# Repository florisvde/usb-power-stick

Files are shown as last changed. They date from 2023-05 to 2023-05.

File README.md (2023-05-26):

# USB Power Stick
The USB Power Stick is a USB Stick to control power (up to 1 A) to a USB powered device from a PC or SBC.

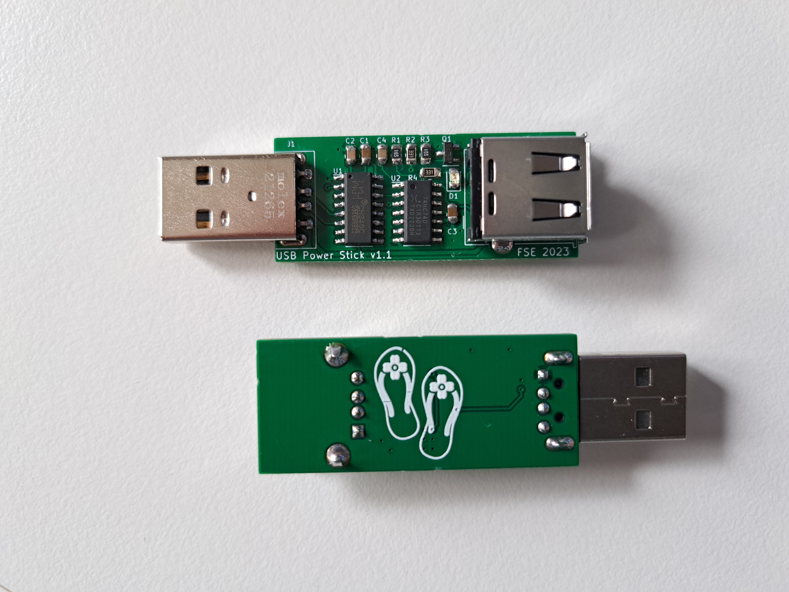
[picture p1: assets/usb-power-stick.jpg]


## Motivation
The Stick is inspired by the common [USB relay sticks](https://aliexpress.com/item/4001216792789.html). 
But using that stick to switch USB power on and off is messy: it requires cutting a USB extention cord, connecting the relay in between and takes up two USB ports. Leading to contraptions like this:

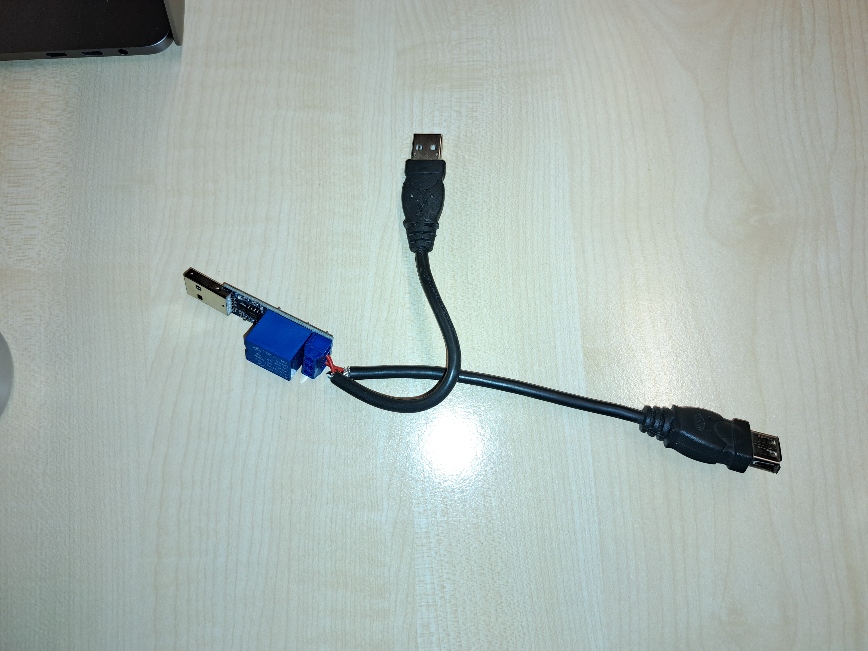
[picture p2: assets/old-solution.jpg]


The USB Power Stick solves that problem neatly by providing the switched power on a USB Type A socket. 

The Stick is used to turn an [IKEA HÅRTE](https://www.ikea.com/nl/nl/p/harte-led-bureaulamp-zwart-zilverkleur-20527242/) light on and off using a Python script running on a Raspberry Pi. The light is used to illuminate a 3D printer, controlled by Octoprint, so a webcam can track the printer's progression during the night.

## How does it work
Take a look at the [PDF of the schematic](https://github.com/florisvde/usb-power-stick/blob/main/KiCad/usb-power-stick/usb-power-stick-schematic.pdf). 
The Stick makes use of a USB to serial converter, a flip flop and an output transistor to switch power on and off to the device connected to the Stick's output. The Stick does not provide USB connectivity to the Stick's output.

The RTS line of the serial converter can be controlled from a computer while the port is open. Therefore the RTS line is connected to the flip flop's (FF) data input (D) and the TX line to the FF's clock input (C). By sending a character the FF latches the current RTS state to the FF's output (Q), then the port can be closed again. This allows for a script to periodically turn power to the device on or off when needed.

An RC network is connected to the FF's asynchronous ~R input, to make sure the stick starts up in the off state, a so called Power on Reset (PoR) circuit.

## Build your own
You can send the Gerber files (directly downloadable as zip from the [releases page](https://github.com/florisvde/usb-power-stick/releases)) to any PCB manufacturer and have the boards made. The board is designed with manual assembly in mind, all parts are easily soldered using a standard soldering iron, fine solder and a pair of tweezers. For everything but the passives a shop link is provided in the [Bill of Materials (BOM)](https://github.com/florisvde/usb-power-stick/blob/main/KiCad/usb-power-stick/usb-power-stick-bom.md).
Pay attention to the pin 1 marker (triangle) of D1: the silk screened triangle is correct, the silk screened outline of the part is not!

## Use it
1. Install [Python](https://www.python.org/downloads/) for your OS.
1. Install the [PySerial package](https://pypi.org/project/pyserial/).
1. Plug the Stick into an computer.
1. Find the Stick's *device dev path* (Unix) by running `ls /dev/ttyUSB*` or *COM port* (Windows) by going to Device Manager.
1. Clone or download this repository.
1. Edit the `stick_on.py` and `stick_off.py` files to use the correct device dev path or COM port.
1. In the directory containing the scripts, run `python stick_on.py` to turn power to the load on, and run `python stick_off.py` to turn power to the load off.

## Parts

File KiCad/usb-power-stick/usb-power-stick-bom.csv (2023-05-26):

Reference | Value | Footprint | Datasheet | Farnell | link | Qty
C1, C3 | 100n | Resistor_SMD:R_0805_2012Metric | ~ | ~ | ~ | 2
C2 | 10n | Resistor_SMD:R_0805_2012Metric | ~ | ~ | ~ | 1
C4 | 1u | Resistor_SMD:R_0805_2012Metric | ~ | ~ | ~ | 1
D1 | LED | LED_SMD:LED_0805_2012Metric | https://www.farnell.com/datasheets/622356.pdf | 1318244 | https://nl.farnell.com/1318244 | 1
J1 | 48037-0001 | kicad_custom_parts:Molex_48037-0001 | https://www.japanese.molex.com/content/dam/molex/molex-dot-com/products/automated/en-us/salesdrawingpdf/480/48037/480370001_sd.pdf | 2067044 | https://nl.farnell.com/2067044 | 1
J2 | 67643-0910 | Connector_USB:USB_A_Molex_67643_Horizontal | https://www.japanese.molex.com/content/dam/molex/molex-dot-com/products/automated/en-us/salesdrawingpdf/676/67643/676430910_sd.pdf | 1450206 | https://nl.farnell.com/1450206 | 1
Q1 | IRLML2803TRPBF | Package_TO_SOT_SMD:SOT-23 | https://www.infineon.com/dgdl/Infineon-IRLML2803-DataSheet-v01_01-EN.pdf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 | 9102701 | https://nl.farnell.com/9102701 | 1
R1, R3 | 10k | Resistor_SMD:R_0805_2012Metric | ~ | ~ | ~ | 2
R2, R4 | 330 | Resistor_SMD:R_0805_2012Metric | ~ | ~ | ~ | 2
U1 | CH340C | Package_SO:SOIC-16_3.9x9.9mm_P1.27mm | http://www.wch-ic.com/downloads/CH340DS1_PDF.html |  | https://www.lcsc.com/product-detail/USB-ICs_WCH-Jiangsu-Qin-Heng-CH340C_C84681.html | 1
U2 | 74HC74 | Package_SO:SOIC-14_3.9x8.7mm_P1.27mm | https://assets.nexperia.com/documents/data-sheet/74HC_HCT74.pdf | 1201317 | https://nl.farnell.com/1201317 | 1

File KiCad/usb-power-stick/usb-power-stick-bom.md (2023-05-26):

| Reference	| Value 			| Farnell	| Quantity	| Shop link 																					| Datasheet link 	|
| --- | ---		| ---	| ---	| ---	| ---	|
| C1, C3 | 100n 				| - 		| 2 		| - 																							| - 				|
| C2		| 10n				| -			| 1			| - 																							| - 				|
| C4		| 1u				| -			| 1			| - 																							| - 				|
| D1[^1]	| LED				| 1318244	| 1			| [Farnell](https://nl.farnell.com/1318244) 													| [Datasheet](https://www.farnell.com/datasheets/622356.pdf) |
| J1		| 48037-0001		| 2067044	| 1			| [Farnell](https://nl.farnell.com/2067044) 													| [Datasheet](https://www.japanese.molex.com/content/dam/molex/molex-dot-com/products/automated/en-us/salesdrawingpdf/480/48037/480370001_sd.pdf) |
| J2		| 67643-0910		| 1450206	| 1			| [Farnell](https://nl.farnell.com/1450206) 													| [Datasheet]( https://www.japanese.molex.com/content/dam/molex/molex-dot-com/products/automated/en-us/salesdrawingpdf/676/67643/676430910_sd.pdf) |
| Q1		| IRLML2803TRPBF	| 9102701	| 1			| [Farnell](https://nl.farnell.com/9102701) 													| [Datasheet](https://www.infineon.com/dgdl/Infineon-IRLML2803-DataSheet-v01_01-EN.pdf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) |
| R1, R3	| 10k				| -			| 2			| - 																							| - 				|
| R2, R4	| 330				| -			| 2			| -	 																							| - 				|
| U1		| CH340C			| -			| 1			| [LCSC](https://www.lcsc.com/product-detail/USB-ICs_WCH-Jiangsu-Qin-Heng-CH340C_C84681.html) 	| [Datasheet](http://www.wch-ic.com/downloads/CH340DS1_PDF.html) |
| U2		| 74HC74			| 1201317	| 1			| [Farnell](https://nl.farnell.com/1201317)														| [Datasheet](https://assets.nexperia.com/documents/data-sheet/74HC_HCT74.pdf) |

[^1]: The Kingbright KP-2012SRC-PRV LED is End of Life (EOL). Kingbright recommends the [KP-2012SURCK](https://nl.farnell.com/1318245) as an alternative.

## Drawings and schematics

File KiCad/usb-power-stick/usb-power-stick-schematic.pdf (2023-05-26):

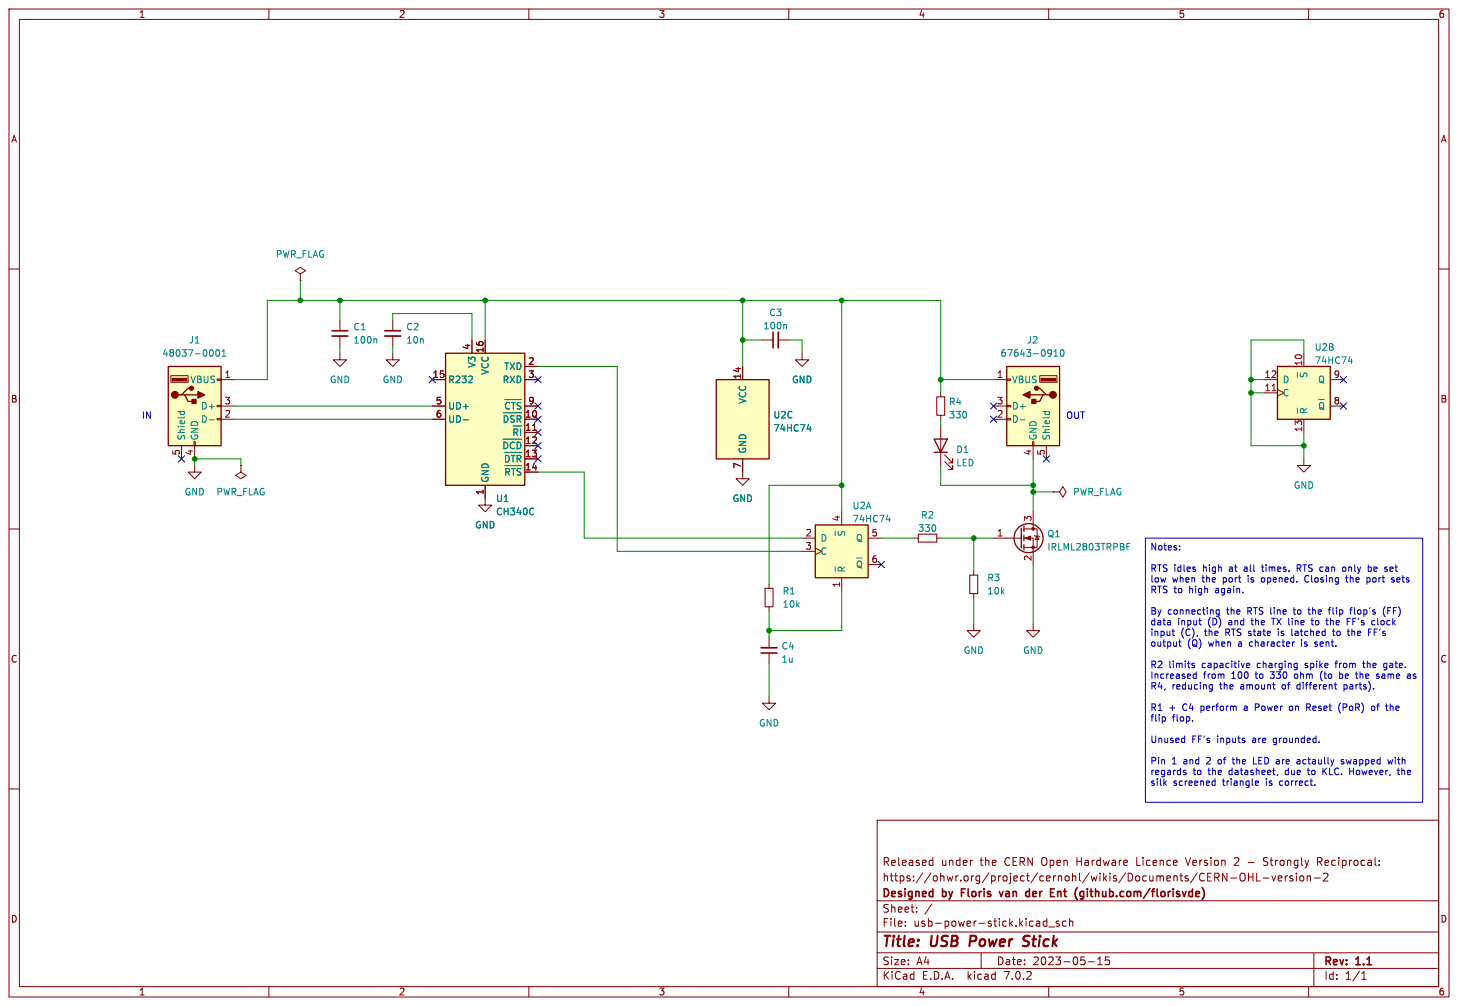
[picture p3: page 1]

1 ~{DSR} 10 ~{RI} 11 ~{DCD} 12 ~{DTR} 13 ~{RTS} 14 R232 15 VCC 16 TXD 2 RXD 3 V3

low when the port is opened. Closing the port sets RTS to high again.

Id: 1/1 Title: USB Power Stick

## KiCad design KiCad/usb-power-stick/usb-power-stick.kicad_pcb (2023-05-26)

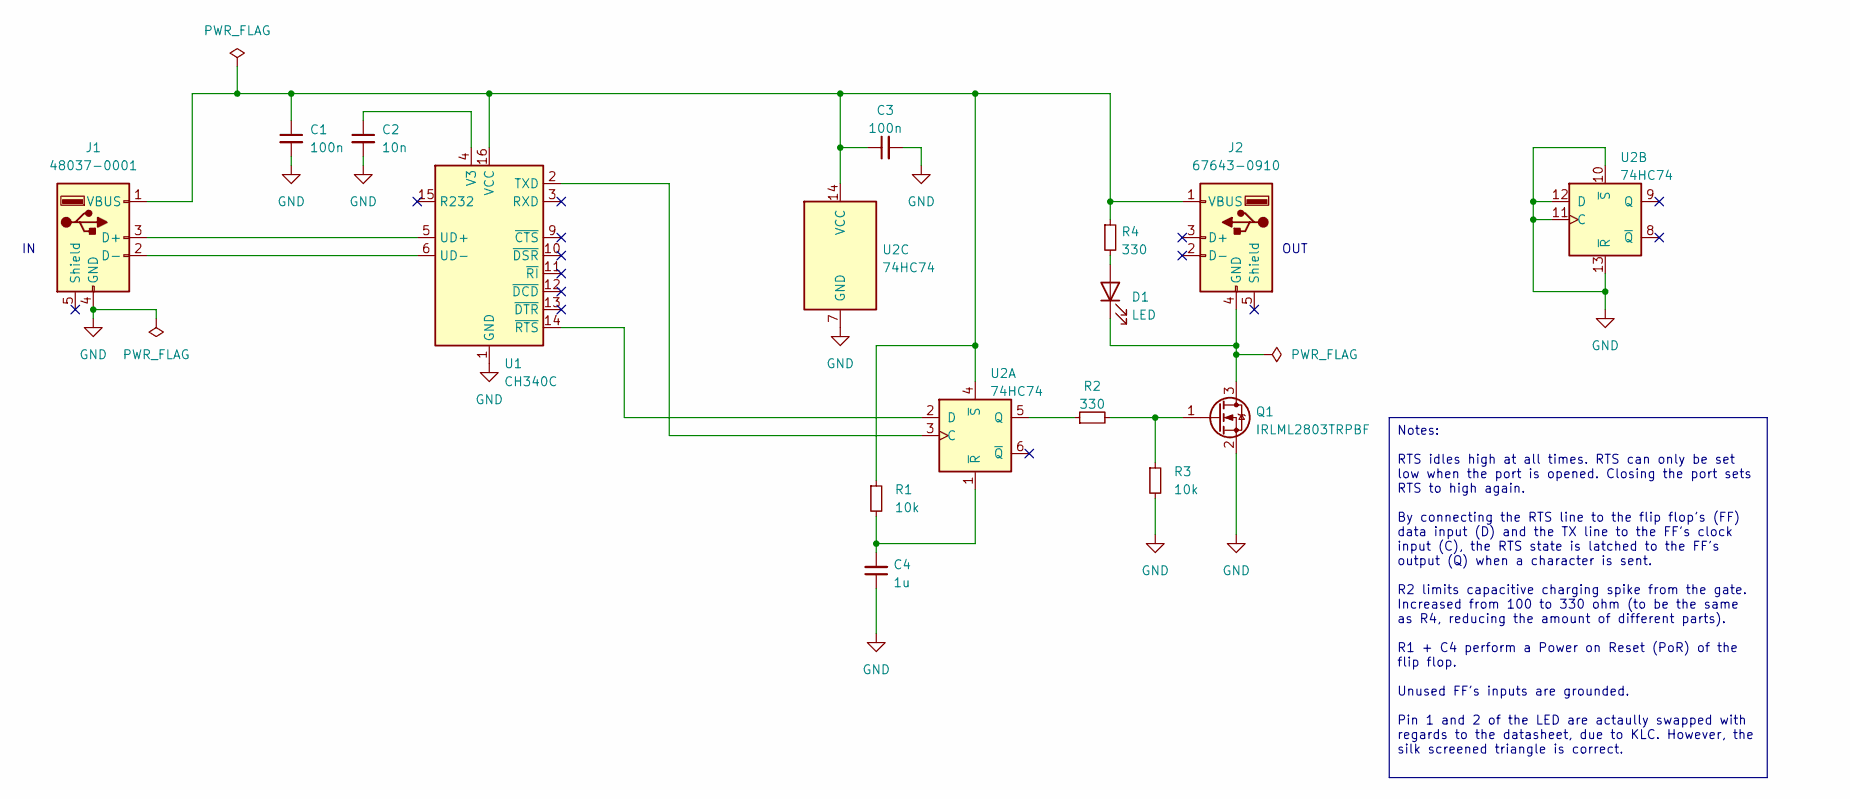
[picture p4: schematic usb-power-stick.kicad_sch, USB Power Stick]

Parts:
C1, C3: 100n; R_0805_2012Metric
C2: 10n; R_0805_2012Metric
C4: 1u; R_0805_2012Metric
D1: LED; LED_0805_2012Metric; Farnell 1318244
J1: 48037-0001; Molex_48037-0001; Farnell 2067044
J2: 67643-0910; USB_A_Molex_67643_Horizontal; Farnell 1450206
Q1: IRLML2803TRPBF; SOT-23; Farnell 9102701
R1, R3: 10k; R_0805_2012Metric
R2, R4: 330; R_0805_2012Metric
U1: CH340C; SOIC-16_3.9x9.9mm_P1.27mm
U2: 74HC74; SOIC-14_3.9x8.7mm_P1.27mm; Farnell 1201317

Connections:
GND: C1.2, C2.2, C3.2, C4.1, J1.4 (GND), Q1.2 (S), R3.2, U1.1 (GND), U2.7 (GND), U2.10 (~S), U2.11 (C), U2.12 (D), U2.13 (~R)
unnamed: C1.1, C3.1, J1.1 (VBUS), J2.1 (VBUS), R1.1, R4.1, U1.16 (VCC), U2.4 (~S), U2.14 (VCC)
unnamed: C2.1, U1.4 (V3)
unnamed: J1.2 (D-), U1.6 (UD-)
unnamed: J1.3 (D+), U1.5 (UD+)
unnamed: D1.1 (K), J2.4 (GND), Q1.3 (D)
unnamed: Q1.1 (G), R2.2, R3.1
unnamed: R2.1, U2.5 (Q)
unnamed: D1.2 (A), R4.2
unnamed: U1.2 (TXD), U2.3 (C)
unnamed: U1.14 (~RTS), U2.2 (D)
unnamed: C4.2, R1.2, U2.1 (~R)

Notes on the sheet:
Notes: RTS idles high at all times. RTS can only be set low when the port is opened. Closing the port sets RTS to high again. By connecting the RTS line to the flip flop's (FF) data input (D) and the TX line to the FF's clock input (C), the RTS state is latched to the FF's output (Q) when a charact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
OUT

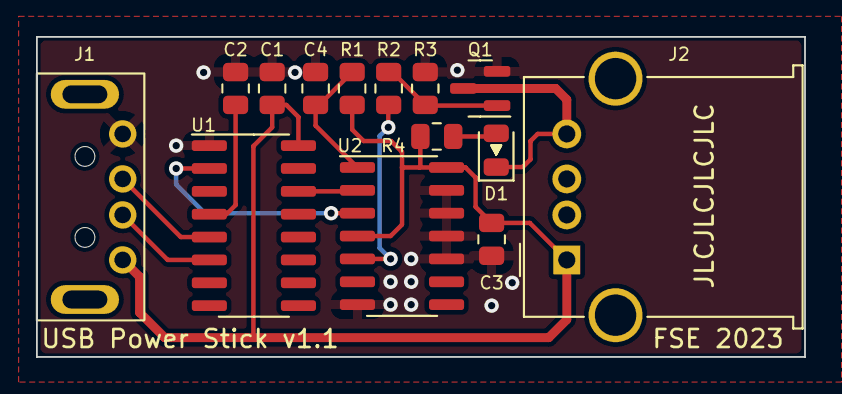
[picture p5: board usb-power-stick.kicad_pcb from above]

Board: 2 copper layers, 42.7 x 17.8 mm, 14 parts (0 on the bottom side), 12 nets.

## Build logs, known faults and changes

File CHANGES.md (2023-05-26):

# Changes
Documents the changes between hardware versions. Commits are tagged with the version number.
## v1.1:
- Removed transistor inverter and solder jumper.
- Replaced output transistor with an easier to solder one (SOT-723 -> SOT-23).
- Added pull down resistor on the gate of the output transistor.
- Increased inline gate resistor to be the same value as the LED's current limiting resistor.
- Added a 74HC74D flip flop + Power on Reset circuit.
- Added a status LED and current limiting resistor.
- Reannotated the schematic, thus references may not match between v1.0 and v1.1.
## v1.0:
- First version, not on GitHub.
- Used RTS line of the CH340 to directly drive a MOSFET. During testing it was discovered that the RTS line idles high when the serial port is closed, and leaving the port open is problematic, script wise.

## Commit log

2023-05-26 version 1.1 initial commit
    Added version 1.1 of the PCB, the Python scripts, CHANGES file a photo of the PCB. Updated README.
    [usb-power-stick-B_Cu.gbr, usb-power-stick-B_Mask.gbr, usb-power-stick-B_Paste.gbr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]
2023-05-26 updated README and gitignore
    Updated README with more instructions, a motivation and a picture of the old solution. Adjusted gitignore file to include csv files, so the csv BOM file is added.
    [usb-power-stick-bom.csv]
2023-05-31 fixed stick not turning off on Raspberry Pi
    Closing the port directly after sending the byte did not clock in RTS properly on a Raspberry Pi. Therefore added a delay before closing.

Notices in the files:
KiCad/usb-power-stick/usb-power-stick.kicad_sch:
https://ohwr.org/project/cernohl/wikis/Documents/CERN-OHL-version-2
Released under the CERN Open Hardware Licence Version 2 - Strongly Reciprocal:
